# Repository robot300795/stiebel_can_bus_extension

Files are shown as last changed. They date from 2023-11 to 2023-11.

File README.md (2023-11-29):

<br/>
<p align="center">
  <h3 align="center">Stiebel Eltron Can Sniffer</h3>

  <p align="center">
    Make Your Heat Pump Smarter
    <br/>
    <br/>
  </p>
</p>
<p align="center">
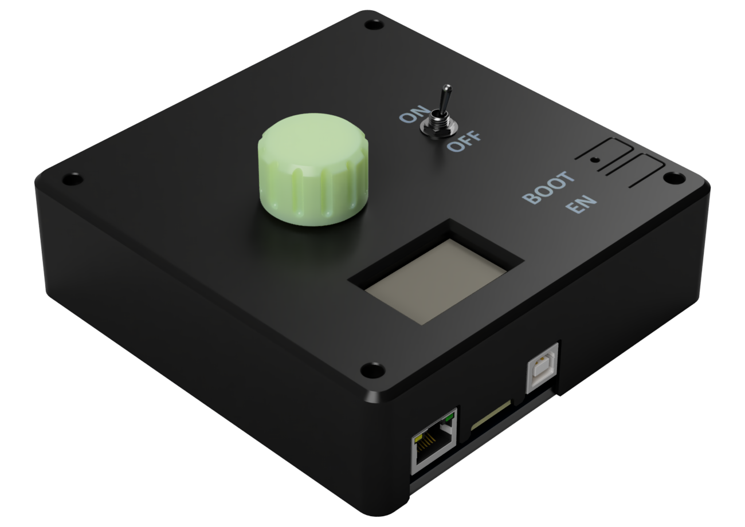
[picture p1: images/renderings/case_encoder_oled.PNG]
  
</p>

## About The Project

<div style="text-align: justify">
This project involves enhancing the capabilities of Stiebel Eltron heat pumps through the development of a custom circuit board. The board interfaces with the heat pump's CAN bus, enabling the extraction and modification of parameters. The primary goal is to optimize the cooling function for smart homes. By altering the communication between the heat pump and the FEK, this project facilitates the utilization of a more efficient cooling function. The designed interface allows data retrieval from the system through serial communication and Modbus, offering flexibility. Additionally, it enables the modification of values sent from the FEK to the heat pump, such as room temperature and humidity. 

A key feature is the potential to relocate the FEK closer to the heat pump, eliminating the necessity for it to be in an excessively cool room. Looking ahead, the interface has the capacity to eventually replace the entire communication system of the FEK. Powered by an ESP32, the board provides a versatile platform with numerous expansion possibilities.
</div>

## Table Of Contents

* [Getting Started](#getting-started)
  * [Hardware](#hardware)
  * [Software](#software)
* [Installation](#installation)
* [Contributing](#contributing)
* [Acknowledgements](#acknowledgements)
* [License](#license)

## Getting Started

<div style="text-align: justify">
The board can be used in two different ways. Simple or interactive configuration. Both versions offer the same possibilities, with the interactive version the board can be shut down more easily, the functionality can be monitored and parameters can be set more comfortably.
</div>

### Hardware

TODO

### Software

TODO 

## Installation

TODO 

## Contributing

Help with expanding the software options is always welcome. The bus dump and the board should allow a complete emulation of the FEK/FET. However, I don't have the time to work this out in detail. A dump of the bus communication can be found [here](utils/bus_dump).

## Acknowledgements

* [juerg5524](https://juerg5524.ch/list_data.php)
* [bullitt186](https://github.com/bullitt186/ha-stiebel-control)
* [mkaiser](https://github.com/mkaiser/ESP32-CAN)

## License

[GPLv3] (https://www.gnu.org/licenses/gpl-3.0.en.html)

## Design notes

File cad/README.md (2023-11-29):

# CAD and Step Files

The casing was designed with Fusion360 and is intended for 3D printing.

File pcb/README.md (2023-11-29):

# PCB

The board is designed with EasyEDA and produced with JLCPCB. Project file and fabrication files can be found here.

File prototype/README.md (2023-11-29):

# Prototype



<div style="text-align: justify">
This is the prototype, the proof of concept, for intercepting messages on the can bus, display, encoder and interfaces.  Not suitable for an environment with vibrations, high temperatures and continuous use. 
</div>

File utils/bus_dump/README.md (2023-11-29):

# Can Bus Dump

<div style="text-align: justify">
The individual Can messages on the bus from heat pumps and FEK direction can be found in the CSV files. The Python file provides a starting point for decoding the messages.
</div>

## Message Decoding
- Each CAN message is made up of 7 bytes.

- The can id, which describes the device sending the message, is specified by Stiebel Eltron and is made up of the combination of the first 4 bits of the first byte and the last 4 bits of the second byte.
```
can_id = 8 * (byte_data[0] & 0b11110000) + (byte_data[1] & 0b00001111)
```

- The last 4 bits of the first byte describe the type of can message. Value 1 describes a request, value 2 a response. Value 0 is a special case and points to byte two. If the second byte value is 0x79, the message sent is a broadcast message that is sent to all bus members at regular intervals.
```
message_type = 8 * (byte_data[0] & 0b00001111)
```

- The third byte is used for extention frame messages, is not currently used and is labeled 0xfa.

- Bytes four and five together form the value id which is sent or received by the bus members.
```
message_id = (byte_data[4] << 8) | byte_data[5]
```

- Bytes six and seven together form the value of the message which is sent or received by the bus participants. In the case of a request message, the bytes are written with the value zero.
```
message_value = (byte_data[6] << 8) | byte_data[7]
```

### Special Messages from FEK/FET
<div style="text-align: justify">
It is interesting to note that some values are not transmitted via the way mentioned above. The FEK/FET sends a CAN message, with the data ID coded via the second byte. The message value is coded as Int16 via bytes 3 and 4. Bytes 5 and 6 are written with the value zero.
</div>

### Examples

TODO

## Note
<div style="text-align: justify">
It should be mentioned that an ISGWeb can also be found on the heat pump page. The heat pump was in normal heating mode at the time of recording.
</div>

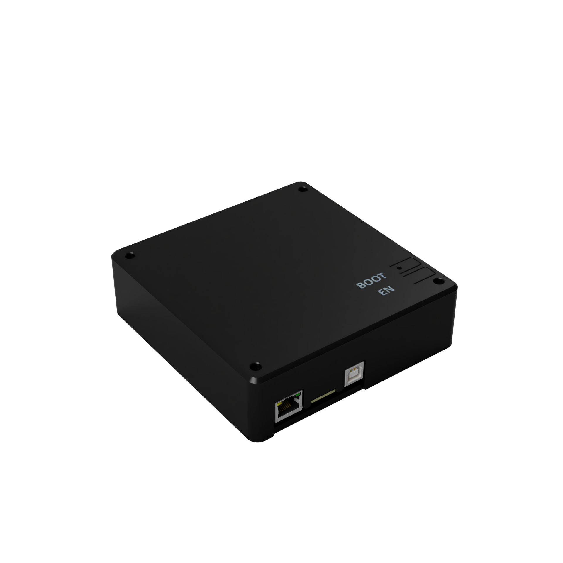
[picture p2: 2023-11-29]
images/renderings/case_simple.PNG

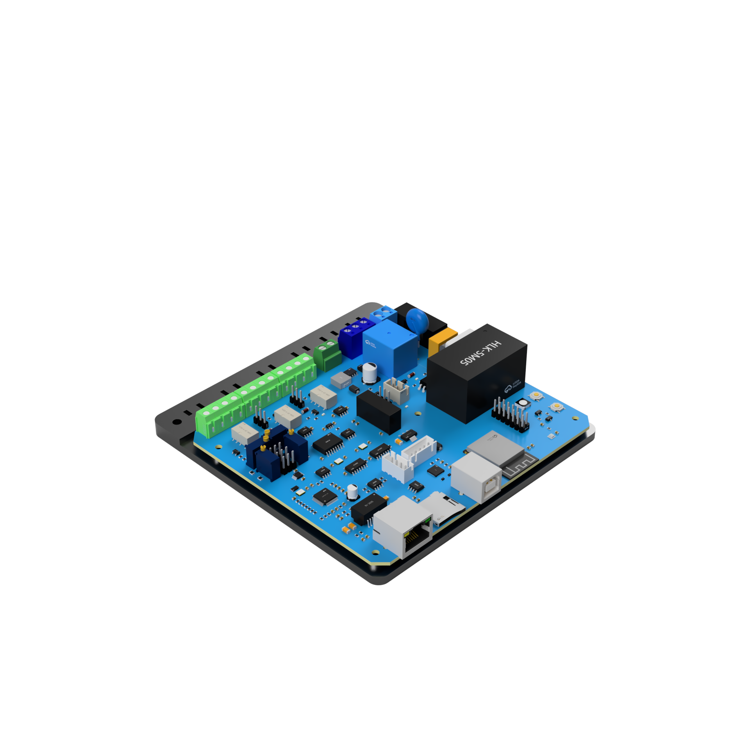
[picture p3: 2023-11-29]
images/renderings/case_open.PNG

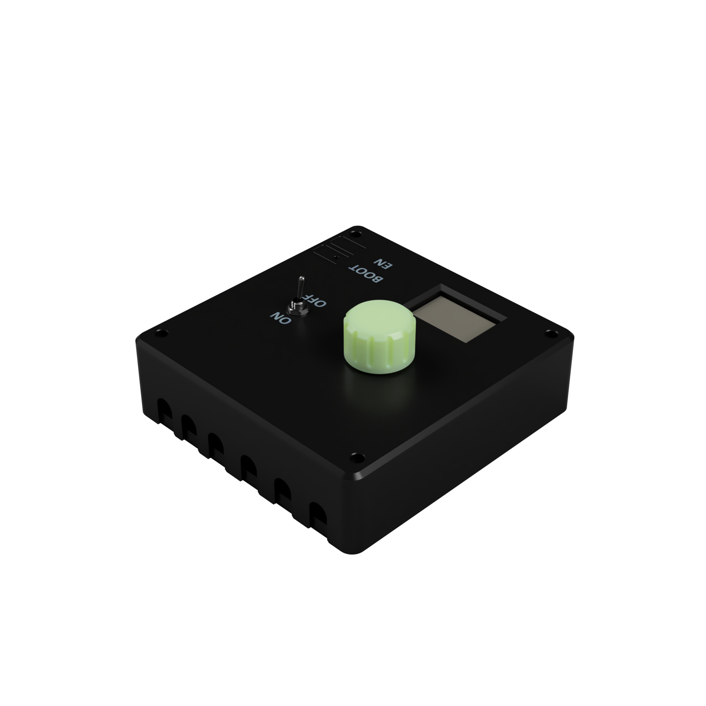
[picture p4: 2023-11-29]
images/renderings/case_encoder_oled_02.PNG

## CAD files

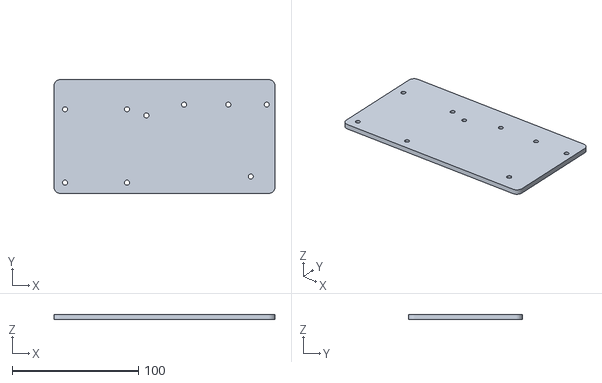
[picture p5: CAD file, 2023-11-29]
prototype/cad/prototype_holder.stl
174.9 x 90.0 x 4.00

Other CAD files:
prototype/cad/stiebel_can_extension_prototype.f3d

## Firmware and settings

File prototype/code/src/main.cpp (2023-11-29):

/**
 * stiebel eltron can telegramm structure
 * length           --> 7 byte as hex values
 * example          --> send (A1 00 fa 07 49) --> revice (D2 00 fa 07 49 xx xx)
 * can-id           --> 8*(A0 & f0) + (00 & 0f) --> 8*(<Digit 1>) + (<Digit 4>) --> can-id 500
 * can-id           --> 8*(d0 & f0) + (00 & 0f) --> 8*(<Digit 1>) + (<Digit 4>) --> can-id 780
 * digit 2.         --> value 1 request, value 2 reponse
 * hex value 2.     --> broadcast --> 0x79 (at regular time intervalls)
 * hex value 3.     --> 0xfa for extention frame (not used)
 * hex value 4.-5.  --> data index values
 * hex value 6.-7.  --> data values (int16)
 * http://juerg5524.ch/list_data.php
 */

/**
 * allowed sender can id: 680 or 700 or 780
 * BE CAREFUL WITH THIS !!!
 * 
 * some values are split between two telegramms
 */

/** Circuit:
  * Spi      --> pins MOSI 16, MISO 14, SCK 15
  * Ethernet --> pins CS 10 
  * SD Card  --> pins CS 4 
  * Can wpm3 --> pins CS 4, INT 2
  * Can fek  --> pins CS 5, INT 3
  * Display  --> pins 20(SDA), 21(SCL)
  * Encoder  --> pins 
*/

// 1664 2 17 282

#include <Arduino.h>
#include <Ethernet.h>
#include <SD.h>
#include <SPI.h>
// Modbus
#include <ArduinoRS485.h> // ArduinoModbus depends on the ArduinoRS485 library
#include <ArduinoModbus.h>
// Can
#include <ACAN2517FD.h>
// digital potentiometer
#include <Adafruit_DS3502.h>
// encoder and display
#include <Wire.h>
#include <menu.h>
#include <menuIO/chainStream.h>
#include <menuIO/encoderIn.h>
#include <menuIO/keyIn.h>
#include <menuIO/u8g2Out.h>

using namespace Menu;

#define pins_led          13
#define pins_watchdog     40
#define pins_relay_can    41
#define pins_relay_sensor 42

#define pins_ethernet_cs  10
// #define pins_ethernet_int 2
#define pins_sd_card_cs   4

#define pins_encoder_clk  19
#define pins_encoder_dt   18
#define pins_encoder_sw   22

#define pins_can_wpm3_cs  53
#define pins_can_wpm3_int 2
#define pins_can_fek_cs   48
#define pins_can_fek_int  3

#define WIRE              Wire
#define fontName          u8g2_font_t0_11_tf
#define fontX             6
#define fontY             11
#define offsetX           0
#define offsetY           3
#define U8_Width          128
#define U8_Height         64
#define MAX_DEPTH         1

const colorDef<uint8_t> colors[6] MEMMODE={
  {{0,0},{0,1,1}},  // bgColor
  {{1,1},{1,0,0}},  // fgColor
  {{1,1},{1,0,0}},  // valColor
  {{1,1},{1,0,0}},  // unitColor
  {{0,1},{0,0,1}},  // cursorColor
  {{1,1},{1,0,0}},  // titleColor
};

// define Modbus server/slave 
// input Mac and IP address
int modbus_slave_id      = 3;
int num_Coils            = 1;
int num_HoldingRegisters = 3;
byte mac[] = {0xDE, 0xAD, 0xBE, 0xEF, 0xFE, 0xED};
IPAddress ip(192, 168, 178, 102);
EthernetServer  ethServer(502);
ModbusTCPServer modbusTCPServer;

// define Can bus
unsigned long can_baudrate = 20100;
bool can_logging_wpm3      = true;
bool can_logging_fek       = true;
ACAN2517FD can_wpm3 (pins_can_wpm3_cs, SPI, pins_can_wpm3_int);
ACAN2517FD can_fek  (pins_can_fek_cs, SPI, pins_can_fek_int);

// define digital potentiometer
int i2c_adress_potentiometer = 0x28;
Adafruit_DS3502 potentiometer = Adafruit_DS3502();

// define SD card and logger file
bool status_sd_card_detected = false;
File File_Datalogger;

// define display and encoder
U8G2_SH1106_128X64_NONAME_F_HW_I2C display(U8G2_R0, U8X8_PIN_NONE);
encoderIn<pins_encoder_clk, pins_encoder_dt> encoder;
encoderInStream<pins_encoder_clk, pins_encoder_dt> encStream(encoder,4);

// keyboard with only one key as the encoder button
keyMap encBtn_map[]={{-pins_encoder_sw, defaultNavCodes[enterCmd].ch}}; //negative pin numbers use internal pull-up, this is on when low
keyIn<1> encButton(encBtn_map);                                         //1 is the number of keys

MENU(mainMenu,
  "Main menu",      doNothing, noEvent, wrapStyle,
  OP("Status",      doNothing, noEvent),
  OP("IP Adress",   doNothing, noEvent),
  OP("Mac Adress",  doNothing, noEvent),
  EXIT("Exit")
);

MENU_INPUTS(in, &encStream, &encButton);

MENU_OUTPUTS(out,MAX_DEPTH,
  U8G2_OUT(display, colors, fontX, fontY, offsetX, offsetY, {0, 0, U8_Width/fontX, U8_Height/fontY}),
  NONE
);

NAVROOT(nav, mainMenu, MAX_DEPTH, in, out);

// internal values
unsigned long baudrate_serial = 115200;
unsigned long watchdog_timer  = millis();
bool watchdog_value           = 0;
bool mode_passthrough         = 0;
int retry                     = 0;


void watchdog(unsigned int interval) {
  unsigned long currentMillis = millis();
  if (currentMillis - watchdog_timer >= interval) {
    // save the last time you blinked the LED
    watchdog_timer = currentMillis;
    // change watchdog state
    if (watchdog_value == LOW) {
      watchdog_value = HIGH;
    } else {
      watchdog_value = LOW;
    }
    // set the LED with the watchdog state
    digitalWrite(pins_led, watchdog_value);
  }
}

/**
 * [0] --> can-id
 * [1] --> message flage (0 broadcast, 1 request, value 2 reponse, 3 invalid)
 * [2] --> data index value
 * [3] --> data (int16)
 */
unsigned int *decode_can_data(CANFDMessage &can_data) {
  static unsigned int decoded_can_data[4];
  if (can_data.len == 7) {
    // [0] --> can-id
    decoded_can_data[0] = (8*(can_data.data[0] & 0xf0)) + (can_data.data[1] & 0x0f);
    // [1] --> message flage (0 broadcast, 1 request, value 2 reponse)
    if ((can_data.data[0] & 0x0f) == 1) {
      decoded_can_data[1] = 1;
    }
    else if ((can_data.data[0] & 0x0f) == 2) {
      decoded_can_data[1] = 2;
    }
    else if (can_data.data[2] == 0x79) {
      decoded_can_data[1] = 0;
    }
    // [2] --> data index value
    decoded_can_data[2] = (can_data.data[3] << 8) + can_data.data[4];
    // [3] --> data (int16)
    decoded_can_data[3] = (can_data.data[5] << 8) + can_data.data[6];
    return decoded_can_data;
  }
  else {
    Serial.println("Warning: Invalid decoding length!");
    static unsigned int decoded_can_data[] = {0x00, 0x03, 0x00, 0x00};
    return decoded_can_data;
  }  
}

void update_can_data(CANFDMessage &can_data, unsigned int data_value) {
  //data value
  can_data.data[5] = highByte(data_value);
  can_data.data[6] = lowByte(data_value);
}

void logging_can_data(CANFDMessage &can_data, const char *filename) {
  if (status_sd_card_detected) {
    unsigned long timestamp = millis();
    File_Datalogger = SD.open(filename, FILE_WRITE);
    if (File_Datalogger) {
      File_Datalogger.print(timestamp); 
      File_Datalogger.print(",");
      File_Datalogger.print(can_data.data[0], HEX); 
      File_Datalogger.print(",");
      File_Datalogger.print(can_data.data[1], HEX); 
      File_Datalogger.print(",");
      File_Datalogger.print(can_data.data[2], HEX); 
      File_Datalogger.print(",");
      File_Datalogger.print(can_data.data[3], HEX); 
      File_Datalogger.print(",");
      File_Datalogger.print(can_data.data[4], HEX); 
      File_Datalogger.print(",");
      File_Datalogger.print(can_data.data[5], HEX); 
      File_Datalogger.print(",");
      File_Datalogger.println(can_data.data[6], HEX);
      File_Datalogger.close();
    }
    else {
      Serial.print("Error: Opening ");
      Serial.print(filename);
      Serial.println("!");
    }
  }
}

void serial_can(CANFDMessage &can_data) {
  Serial.print(can_data.data[0], HEX); 
  Serial.print(" ");
  Serial.print(can_data.data[1], HEX); 
  Serial.print(" ");
  Serial.print(can_data.data[2], HEX); 
  Serial.print(" ");
  Serial.print(can_data.data[3], HEX);
  Serial.print(" ");
  Serial.print(can_data.data[4], HEX);
  Serial.print(" ");
  Serial.print(can_data.data[5], HEX);
  Serial.print(" ");
  Serial.println(can_data.data[6], HEX);
}

void serial_can_decoded(unsigned int decoded_can_data[]) {
  Serial.print(decoded_can_data[0], HEX); 
  Serial.print(" ");
  Serial.print(decoded_can_data[1]); 
  Serial.print(" ");
  Serial.print(decoded_can_data[2]); 
  Serial.print(" ");
  Serial.println(decoded_can_data[3]);
}

void setup() {
  // *** start serial communications and wait for port to open ***
  Serial.begin(baudrate_serial);
  while (!Serial) {
    ; // wait for serial port to connect. Needed for native USB port only
  }

  // *** start spi and i2c communications ***
  SPI.begin();
  Wire.begin();
 
   // *** start ethernet communications and the server ***
  Ethernet.init(pins_ethernet_cs);
  Ethernet.begin(mac, ip);

  // check for ethernet hardware present
  if (Ethernet.hardwareStatus() == EthernetNoHardware) {
    Serial.println("ERROR: Ethernet hardware was not found!");
    while (true) {
      delay(1); // do nothing, no point running without Ethernet hardware
    }
  }
  else {
    Serial.println("INFO: Ethernet hardware was found.");
  }

  // check if ethernet cable is connected
  // only available when using the W5200 and W5500 Ethernet controller chips
  if (Ethernet.linkStatus() == LinkOFF) {
    Serial.println("Warning: Ethernet cable is not connected.");
  }

  // start the server
  ethServer.begin();

  // *** start the Modbus TCP server ***
  if (!modbusTCPServer.begin(modbus_slave_id)) {
    Serial.println("ERROR: Failed to start Modbus TCP Server!");
    while (true) {
      delay(1); // do nothing, no point running without Modbus TCP server
    }
  }
  else {
    Serial.println("INFO: Modbus TCP Server started.");
  }

  // *** configure can communications ***
  Serial.println("Configure ACAN2517FD");
  ACAN2517FDSettings settings (ACAN2517FDSettings::OSC_40MHz, can_baudrate, DataBitRateFactor::x1);
  // Default values are too high for an Arduino Uno that contains 2048 bytes of RAM: reduce them
  settings.mDriverTransmitFIFOSize = 1;
  settings.mDriverReceiveFIFOSize = 1;
  // RAM Usage
  Serial.print("MCP2517FD RAM Usage: ");
  Serial.print(settings.ramUsage());
  Serial.println(" bytes");

  // *** start can communications for wpm3 side ***
  const uint32_t errorCode_wpm3 = can_wpm3.begin(settings, []{can_wpm3.isr();});
  if (errorCode_wpm3 == 0) {
    Serial.println("INFO: Can Bus for WPM3 side started with settings: ");
    Serial.print("Bit Rate prescaler: ");
    Serial.println(settings.mBitRatePrescaler);
    Serial.print("Arbitration Phase segment 1: ");
    Serial.println(settings.mArbitrationPhaseSegment1);
    Serial.print("Arbitration Phase segment 2: ");
    Serial.println(settings.mArbitrationPhaseSegment2);
    Serial.print("Arbitration SJW:");
    Serial.println(settings.mArbitrationSJW);
    Serial.print("Actual Arbitration Bit Rate: ");
    Serial.print(settings.actualArbitrationBitRate ());
    Serial.println(" bit/s") ;
    Serial.print("Exact Arbitration Bit Rate ? ");
    Serial.println(settings.exactArbitrationBitRate () ? "yes" : "no");
    Serial.print("Arbitration Sample point: ");
    Serial.print(settings.arbitrationSamplePointFromBitStart ());
    Serial.println("%") ;
  } else {
    Serial.print("ERROR: Failed to start Can Bus for WPM3 side! Configuration error 0x");
    Serial.println(errorCode_wpm3, HEX);
    while (true) {
      delay(1); // do nothing, no point running without can bus
    }
  }

  // *** start can communications for wpm3 side ***
  const uint32_t errorCode_fek = can_fek.begin(settings, []{can_fek.isr();});
  if (errorCode_wpm3 == 0) {
    Serial.println("INFO: Can Bus for WPM3 side started with settings: ");
    Serial.print("Bit Rate prescaler: ");
    Serial.println(settings.mBitRatePrescaler);
    Serial.print("Arbitration Phase segment 1: ");
    Serial.println(settings.mArbitrationPhaseSegment1);
    Serial.print("Arbitration Phase segment 2: ");
    Serial.println(settings.mArbitrationPhaseSegment2);
    Serial.print("Arbitration SJW:");
    Serial.println(settings.mArbitrationSJW);
    Serial.print("Actual Arbitration Bit Rate: ");
    Serial.print(settings.actualArbitrationBitRate ());
    Serial.println(" bit/s") ;
    Serial.print("Exact Arbitration Bit Rate ? ");
    Serial.println(settings.exactArbitrationBitRate () ? "yes" : "no");
    Serial.print("Arbitration Sample point: ");
    Serial.print(settings.arbitrationSamplePointFromBitStart ());
    Serial.println("%") ;
  } else {
    Serial.print("ERROR: Failed to start Can Bus for WPM3 side! Configuration error 0x");
    Serial.println(errorCode_fek, HEX);
    while (true) {
      delay(1); // do nothing, no point running without can bus
    }
  }

  // *** start digital potentiometer
  /* if (!potentiometer.begin(i2c_adress_potentiometer, &Wire)) {
    Serial.println("ERROR: Couldn't find potentiometer DS3502!");
    while (true) {
      delay(1); // do nothing, no point running without can bus
    }
  }
  else {
    Serial.println("INFO: Potentiometer DS3502 found.");
  } */

  // *** start SD card ***
  // https://docs.arduino.cc/learn/programming/sd-guide
  if (!SD.begin(pins_sd_card_cs)) {
    Serial.println("Warning: No SD Card detected. Logging deactivated!");
    status_sd_card_detected = false;
  }
  else {
    Serial.println("INFO: SD Card detected. Logging activated.");
    status_sd_card_detected = true;
  }

  // configure Modbus 
  // single coil at address 0x00
  // https://github.com/arduino-libraries/ArduinoModbus/blob/master/examples/TCP/EthernetModbusServerLED/EthernetModbusServerLED.ino
  modbusTCPServer.configureCoils(0x00, num_Coils);
  modbusTCPServer.configureHoldingRegisters(0x00, num_HoldingRegisters);

  // configure pins
  pinMode(pins_led, OUTPUT);
  pinMode(pins_relay_can, OUTPUT);
  pinMode(pins_relay_sensor, OUTPUT);

  // activate can relay
  digitalWrite(pins_relay_can, 1);

  // *** setup display ***
  display.begin();
  display.setFont(fontName);
  // disable second option
  mainMenu[1].enabled=disabledStatus;
}

void loop() {
  // listen for incoming clients
  EthernetClient client = ethServer.available();
  
  if (client) {
    // let the Modbus TCP accept the connection 
    modbusTCPServer.accept(client);

    Serial.println("Modbus client connected!");
    while (client.connected()) {
      // watchdog ok --> led blick 1 sec
      watchdog(1000);

      // display input check 
      nav.doInput();

      // poll for Modbus TCP requests, while client connected
      // maybe time delay
      modbusTCPServer.poll();

      // 0. check modbus for new data
      bool status_change_temperatue_outside = (bool) ModbusRTUServer.coilRead(0);
      double value_room_temperature         = (double) ModbusRTUServer.holdingRegisterRead(0) * 0.1;
      double value_room_humidity            = (double) ModbusRTUServer.holdingRegisterRead(1) * 0.1;

      // 1. get can data from wpm3 side
      CANFDMessage can_data_wpm3;
      if (can_wpm3.receive(can_data_wpm3)) { 
        // logging
        if (can_logging_wpm3) {
          logging_can_data(can_data_wpm3, "can_wpm.txt");
        }

        // send data to fek side, with 5 retrys
        retry = 0;
        while(TRUE) {
          if ((can_fek.tryToSend(can_data_wpm3)) || (retry >= 5)) {
            break;
          }
          else {
            retry += 1;
            Serial.print("Transmitted failed: Can WPM3 to Can FEK. Retry ");
            Serial.println(retry);
            unsigned int *decoded_can_data = decode_can_data(can_data_wpm3);
            serial_can_decoded(decoded_can_data);
          }
        }
      }

      CANFDMessage can_data_fek;
      if (can_fek.receive(can_data_fek)) {
        // logging
        if (can_logging_fek) {
          logging_can_data(can_data_fek, "can_fek.txt");
        }

        // change can data 
        unsigned int *decoded_can_data = decode_can_data(can_data_fek);
        if (decoded_can_data[0] == 1538) {
          Serial.println("FEK Side");
          serial_can(can_data_fek);
          serial_can_decoded(decoded_can_data);

          // temperature
          if (can_data_fek.data[2] == 17) { 
            can_data_fek.data[3] = highByte((int) (value_room_temperature * 10));
            can_data_fek.data[4] = lowByte((int) (value_room_temperature * 10));
          }
          // humidity
          if (can_data_fek.data[2] == 117) { 
            can_data_fek.data[3] = highByte((int) (value_room_humidity * 10));
            can_data_fek.data[4] = lowByte((int) (value_room_humidity * 10));
          }
        }

        // send fek data to wpm3 side, with 5 retrys
        retry = 0;
        while(TRUE) {
          if ((can_wpm3.tryToSend(can_data_fek)) || (retry >= 5)) {
            break;
          }
          else {
            retry += 1;
            Serial.print("Transmitted failed: Can FEK to Can WPM3. Retry ");
            Serial.println(retry);
            unsigned int *decoded_can_data = decode_can_data(can_data_fek);
            serial_can_decoded(decoded_can_data);
          }
        }
      }

      // outside temperature change
      if (status_change_temperatue_outside) {
        digitalWrite(pins_relay_sensor, 1);
        double value_temperatue_outside = (double) ModbusRTUServer.holdingRegisterRead(2) * 0.1;
        // digital poti output change
      }
      else {
        // passthrough temperature sensor
        digitalWrite(pins_relay_sensor, 0);
      }

      // 7. update display
      //only draw if menu changed for gfx device
      if (nav.changed(0)) {
        //change checking leaves more time for other tasks
        display.firstPage();
        do nav.doOutput(); 
        while(display.nextPage());
      }
    }
    Serial.println("Modbus client disconnected!");
  }
  else {
    // Serial.println("No Modbus client connected! Passthrough mode!");
    // watchdog ok --> led blick 0.5 sec
    watchdog(250);

    // display input check 
    nav.doInput();

    // 1. get can data from wpm3 side
    CANFDMessage can_data_wpm3;
    if (can_wpm3.receive(can_data_wpm3)) {      
      // logging
      if (can_logging_wpm3) {
        logging_can_data(can_data_wpm3, "can_wpm.txt");
      }

      // send data to fek side, with 5 retrys
      retry = 0;
      while(TRUE) {
        if ((can_fek.tryToSend(can_data_wpm3)) || (retry >= 5)) {
          break;
        }
        else {
          retry += 1;
          Serial.print("Transmitted failed: Can WPM3 to Can FEK. Retry ");
          Serial.println(retry);
          unsigned int *decoded_can_data = decode_can_data(can_data_wpm3);
          serial_can_decoded(decoded_can_data);
        }
      }
    }

    CANFDMessage can_data_fek;
    if (can_fek.receive(can_data_fek)) {
      // logging
      if (can_logging_fek) {
        logging_can_data(can_data_fek, "can_fek.txt");
      }

      // change data 
      unsigned int *decoded_can_data = decode_can_data(can_data_fek);
      if (decoded_can_data[0] == 1538) {
        Serial.println("FEK Side");
        serial_can(can_data_fek);
        serial_can_decoded(decoded_can_data);

        if (can_data_fek.data[2] == 17) { 
          can_data_fek.data[3] = highByte(245);
          can_data_fek.data[4] = lowByte(245);

          serial_can(can_data_fek);
        }
      }

      // send fek data to wpm3 side, with 5 retrys
      retry = 0;
      while(TRUE) {
        if ((can_wpm3.tryToSend(can_data_fek)) || (retry >= 5)) {
          break;
        }
        else {
          retry += 1;
          Serial.print("Transmitted failed: Can FEK to Can WPM3. Retry ");
          Serial.println(retry);
          unsigned int *decoded_can_data = decode_can_data(can_data_fek);
          serial_can_decoded(decoded_can_data);
        }
      }     
    }

    // passthrough temperature sensor
    digitalWrite(pins_relay_sensor, 0);

    // 7. update display
    //only draw if menu changed for gfx device
    if (nav.changed(0)) {
      //change checking leaves more time for other tasks
      display.firstPage();
      do nav.doOutput(); 
      while(display.nextPage());
    }
  }
}
